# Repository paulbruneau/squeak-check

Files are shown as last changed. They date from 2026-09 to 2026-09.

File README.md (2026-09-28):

# Squeak Check!

A bench tester for Midway's Cheap Squeak Deluxe, Sounds Good and Turbo Cheap Squeak arcade sound boards (Spy Hunter, Rampage, Xenophobe, Sarge and more). Power a sound board on the bench, dial a sound 0–F, press PLAY, and hear it on line out, with no game CPU board, harness or cabinet.

By Ethical Paul.

**Website:** the full write-up (how the boards work, pinouts, hook-up diagram, history) is in `index.html`, published with GitHub Pages.

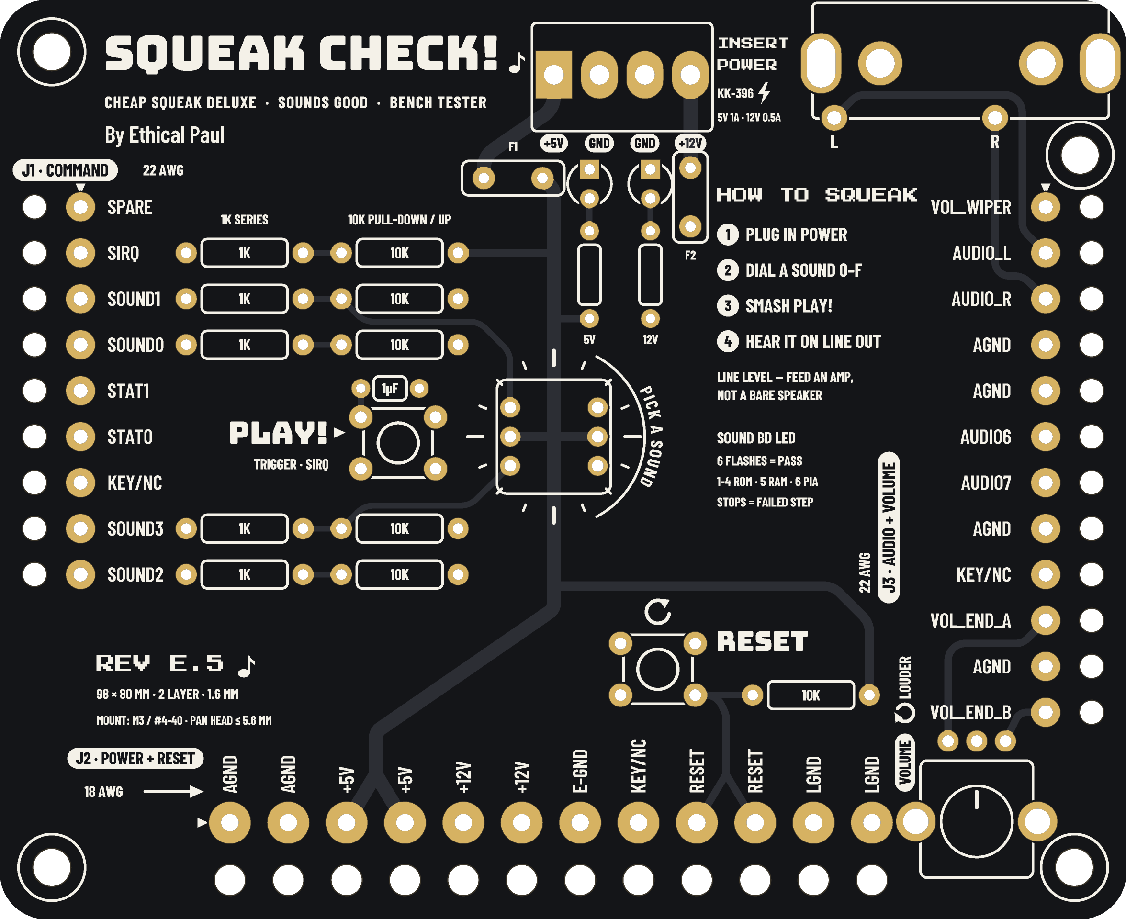
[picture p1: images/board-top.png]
Squeak Check Rev E.5


## Files

| Path | What it is |
| --- | --- |
| `fab/SqueakCheck_RevE5_Gerbers.zip` | Gerbers and drill files, Rev E.5 (98 × 80 mm, 2 layers, 1.6 mm) |
| `fab/Schematic_RevE5.pdf` | Schematic, drawn from and checked against the board netlist |
| `fab/KiCad/` | KiCad 8 schematic and PCB, generated from the board data (refill the zone and run DRC after opening) |
| `fab/BOM.csv` | Bill of materials with Mouser part numbers |
| `fab/Harness_Pin_Map.csv` | Every harness hole: connector, pin, label, net, position |
| `fab/README.txt` | Revision history and verification notes |
| `index.html`, `images/` | The website |

## Ordering boards

Upload the Gerber zip to any 2-layer PCB fab: FR-4, 1.6 mm, 1 oz copper, any mask colour, white silk, HASL or ENIG.

## Rights

© 2026 Ethical Paul. All rights reserved. No license is granted yet; ask before reusing the files.

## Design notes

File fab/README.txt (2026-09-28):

SQUEAK CHECK! — Midway sound board bench tester — REV E.5
By Ethical Paul
=========================================================

WHAT IT TESTS
-------------
Verified against the original Bally/Midway schematics (Spy Hunter, Rampage/Star
Guards and Sarge manuals). All three boards share the same J1/J2/J3 pinout and the
same command interface (4 sound-select bits + SIRQ strobe, 2 status bits back):

  Cheap Squeak Deluxe  A080-91671 (68000)   Spy Hunter, Turbo Tag (proto)
  Sounds Good          A080-91671-G000 PCB  Rampage, Power Drive, Star Guards,
                       (a later revision of  Xenophobe, Spy Hunter II, Blasted,
                        the same bare board) Intl. Team Laser (proto)
  Turbo Cheap Squeak   (6809)               Sarge, Max RPM, Demolition Derby,
                                            Spy Hunter II (2nd board)

NOT compatible: Super Sound I/O (SSIO), and the Williams System 11 boards in
Arch Rivals / Pigskin / Tri-Sports. Pinball-era Bally boards (Cheap Squeak,
Sounds Deluxe, pinball TCS) use different harnesses and were not checked.

REV E.5: POWER PROTECTION AND INDICATORS (review feedback).
- F1 (Bourns MF-R135, 1.35 A hold) on +5 V and F2 (MF-R050, 0.5 A hold) on +12 V:
  resettable fuses right after the power header, so a shorted sound board
  can't cook the tester's traces or connector.
- D1/D2 green LEDs on +5 V and +12 V, AFTER the fuses (1k / 3.3k, ~3 mA): a dark
  LED means no supply or a tripped fuse.
- Suggested supply printed on the board: 5 V 1 A, 12 V 0.5 A (estimated from
  the sound board's chips; measure your own board).
- Mounting note on the silk: M3 or #4-40, pan head no bigger than 5.6 mm.
- LED self-test legend moved into the how-to panel to make room.
Harness holes, pin order, names and every sound-board signal are unchanged.

REV E.4: BOARD NARROWED 108 -> 98 MM. J1 stays on the left edge; the resistor
block tucked in against the J1 labels and everything else slid left (J2, J3, pot,
RCA jacks and power header move as groups, with pitches, hole sizes, pin order and
labels all unchanged). +12V now runs between the SOUND2 trace and the RESET
button on the back. Netlist identical to E.3.

REV E.3: VOLUME POT ON THE BOARD. The J5 A/W/B wire pads are gone; RV1 (Bourns
PTV09A-4020U-B102, 1k linear, 9 mm, vertical 20 mm knurled shaft
you turn by hand - no knob needed) sits in the
bottom-right corner, wired pin 1 = VOL_END_B (J3-12), pin 2 = VOL_WIPER (J3-1),
pin 3 = VOL_END_A (J3-10) so turning it CLOCKWISE = LOUDER (the MC3340 attenuates
more as the wiper voltage rises). Its two side tabs are soldered to ground for
strength. Every other net, hole and label is unchanged from E.2. Part numbers in
BOM.csv are Mouser numbers.

REV E.2 (layout): PLAY button and its debounce cap moved right beside the hex
dial; "By Ethical Paul" added under the title. No circuit change from E.1.

REV E.1 CHANGES (from Rev E / Rev D5)
------------------------------------
1. RESET POLARITY FIXED. J2-9/10 is active-LOW on all three boards (e.g. CSD:
   100k pull-up -> 40106 -> 74LS04 -> diodes pull the 68000 RST/HALT low). Rev D5
   held RESET low through 10k, which would keep the board in reset permanently.
   Now: RRST (10k) pulls RESET up to +5V; the RESET button pulls it to GND.
2. SIRQ polarity hardwired "fire low"; JP1 removed. All three boards idle SIRQ
   high (100k on-board pull-up) and the same game hardware drives them with the
   same signal (Spy Hunter II feeds a Sounds Good and a TCS from the same control
   bits). RIRQ (10k) pulls SIRQ up to +5V; PLAY pulls it to GND.
3. PLAY debounce: C1 1 uF across the button (~10 ms with RIRQ).
4. E-GND (J2-7) tied to GND. Sounds Good grounds it on-board; CSD/TCS use it as
   the return for their input filter capacitors.
Harness hole sizes, pin order, duplicate pins and all silk names are unchanged.

USING IT
--------
Power-up: the sound board's green LED flashes once per passed self-test:
  1-4 = ROMs (U7, U8, U17, U18), 5 = RAM (U6, U16), 6 = PIA (U9).
  Six flashes = pass. Where it stops = the failed step. (Star Guards manual.)

Red TEST button ON the sound board: wired to the 68000's interrupt lines
(pulls IPL0-2 -> level 7). What it does is decided by that game's ROMs. On the
sister pinball boards it plays one fixed test sound (a "bong" or an explosion)
or just reboots the board; it is not a cycle through all sounds.

Sound numbers: the connector carries 4 bits per strobe. The boards' firmware
generally treats commands as pairs of nibbles ("command followed by command"),
so a single dial+PLAY press sends one nibble. Try single presses first; for other
sounds, dial the first nibble, press PLAY, dial the second, press PLAY. The exact
command list lives in each game's sound ROMs and is not documented in MAME.

Start with the VOLUME knob turned down (fully counter-clockwise). Line-level mono audio
appears on both RCA jacks; feed an amplifier or powered speaker.

VERIFICATION
------------
Raster DRC at 0.04 mm: 0 shorts, 0 opens, 0 clearance < 0.30 mm, 0 islands.
Netlist = Rev D5 original + the four E.1 changes + the on-board pot (E.3),
checked pin by pin.
Gerbers re-read with gerbonara and diffed against the checked geometry:
0 mismatches on copper, mask and silk. (No KiCad/Altium DRC available here —
preview the zip in your fab's Gerber viewer before ordering.)

ORDERING
--------
2 layers, FR-4, 1.6 mm, 1 oz, any mask colour, white silk, ENIG or HASL.
98 x 80 mm. Upload the Gerbers/ folder zipped.

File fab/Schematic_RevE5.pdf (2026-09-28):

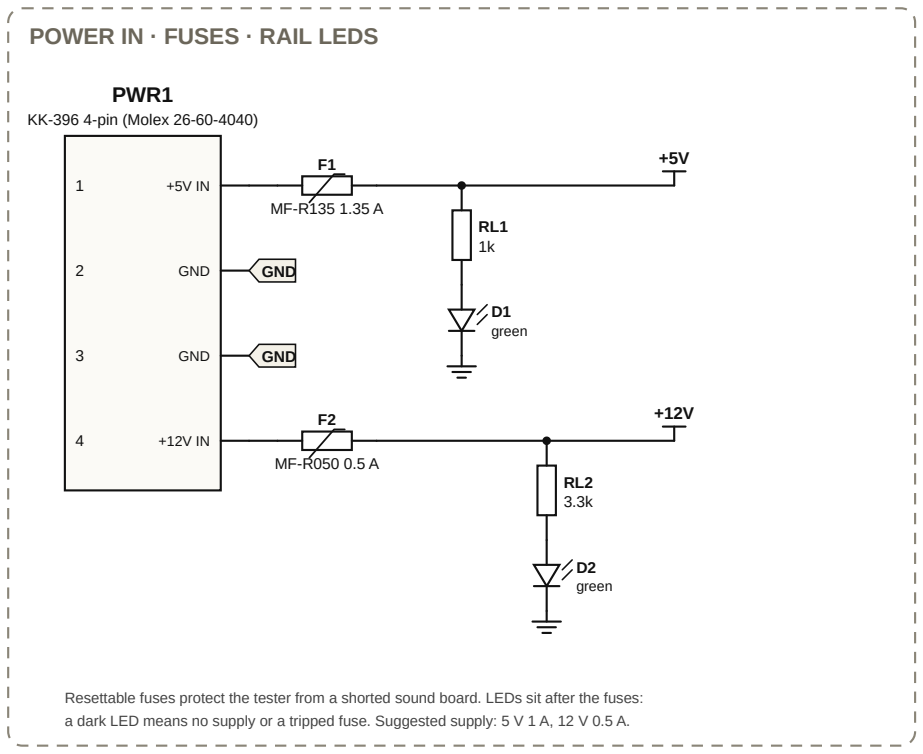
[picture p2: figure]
POWER IN · FUSES · RAIL LEDS; PWR1; KK-396 4-pin (Molex 26-60-4040); GND; D1 green; D2 green

Resettable fuses protect the tester from a shorted sound board. LEDs sit after the fuses: a dark LED means no supply or a tripped fuse. Suggested supply: 5 V 1 A, 12 V 0.5 A.

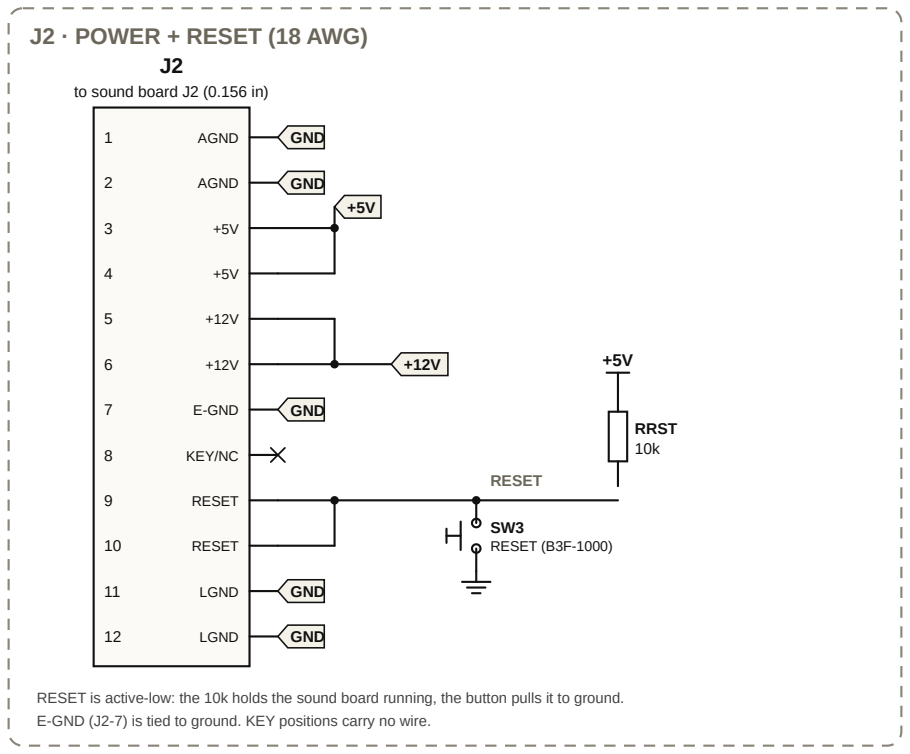
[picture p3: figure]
J2 · POWER + RESET (18 AWG) J2; to sound board J2 (0.156 in); AGND; E-GND; KEY/NC; RESET; LGND; GND; RRST 10k; SW3 RESET (B3F-1000)

RESET is active-low: the 10k holds the sound board running, the button pulls it to ground. E-GND (J2-7) is tied to ground. KEY positions carry no wire.

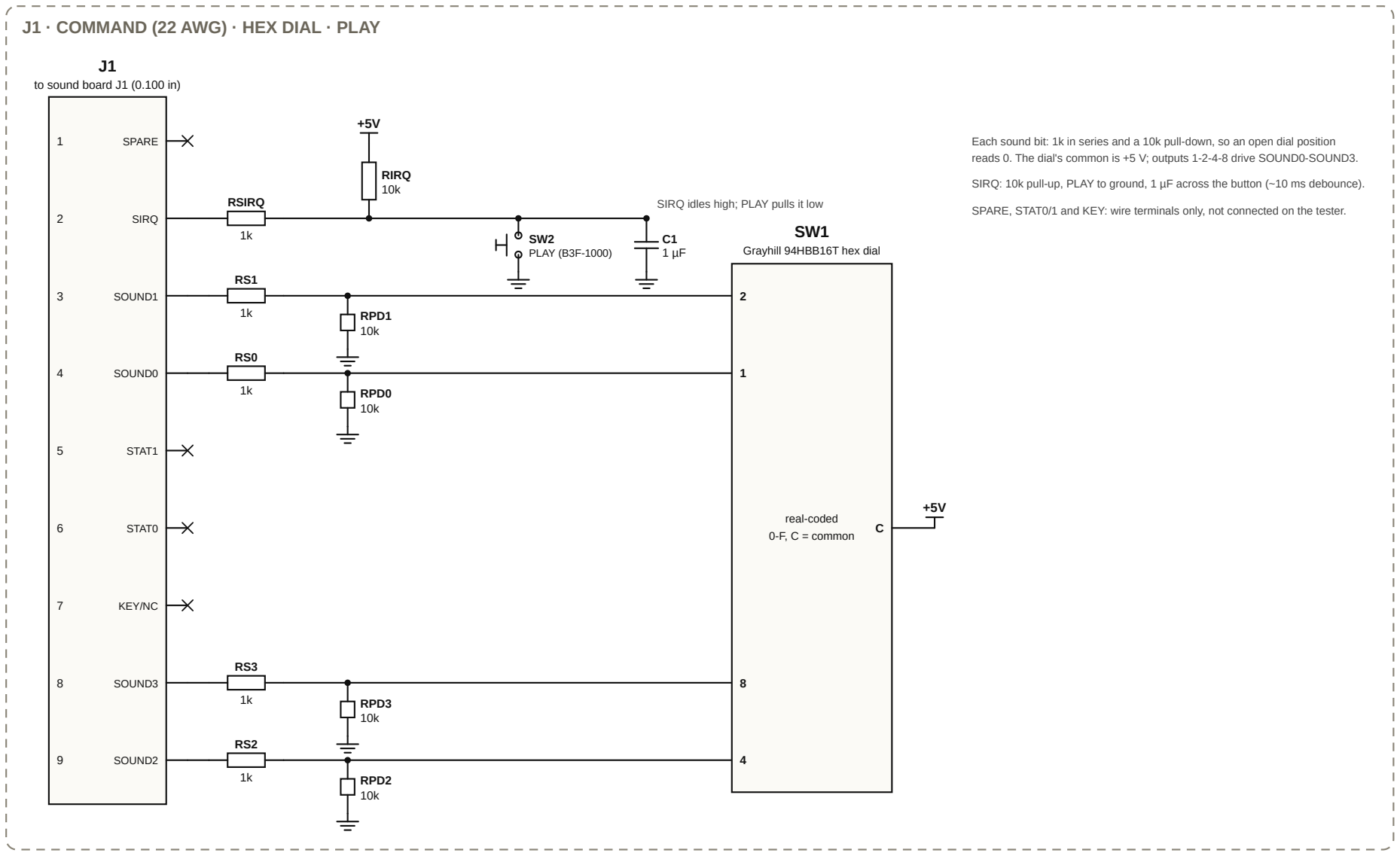
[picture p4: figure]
J1 · COMMAND (22 AWG) · HEX DIAL · PLAY; to sound board J1 (0.100 in); SPARE; SIRQ; SOUND1; SOUND0; STAT1; STAT0; KEY/NC; SOUND3; SOUND2; RPD0; RPD1; RPD2; RPD3; Grayhill 94HBB16T hex dial; real-coded 0-F, C = common; RSIRQ; RIRQ 10k; SW2 PLAY (B3F-1000); SIRQ idles high; PLAY pulls it low

Each sound bit: 1k in series and a 10k pull-down, so an open dial position reads 0. The dial's common is +5 V; outputs 1-2-4-8 drive SOUND0-SOUND3.

SPARE, STAT0/1 and KEY: wire terminals only, not connected on the tester.

SIRQ: 10k pull-up, PLAY to ground, 1 µF across the button (~10 ms debounce).

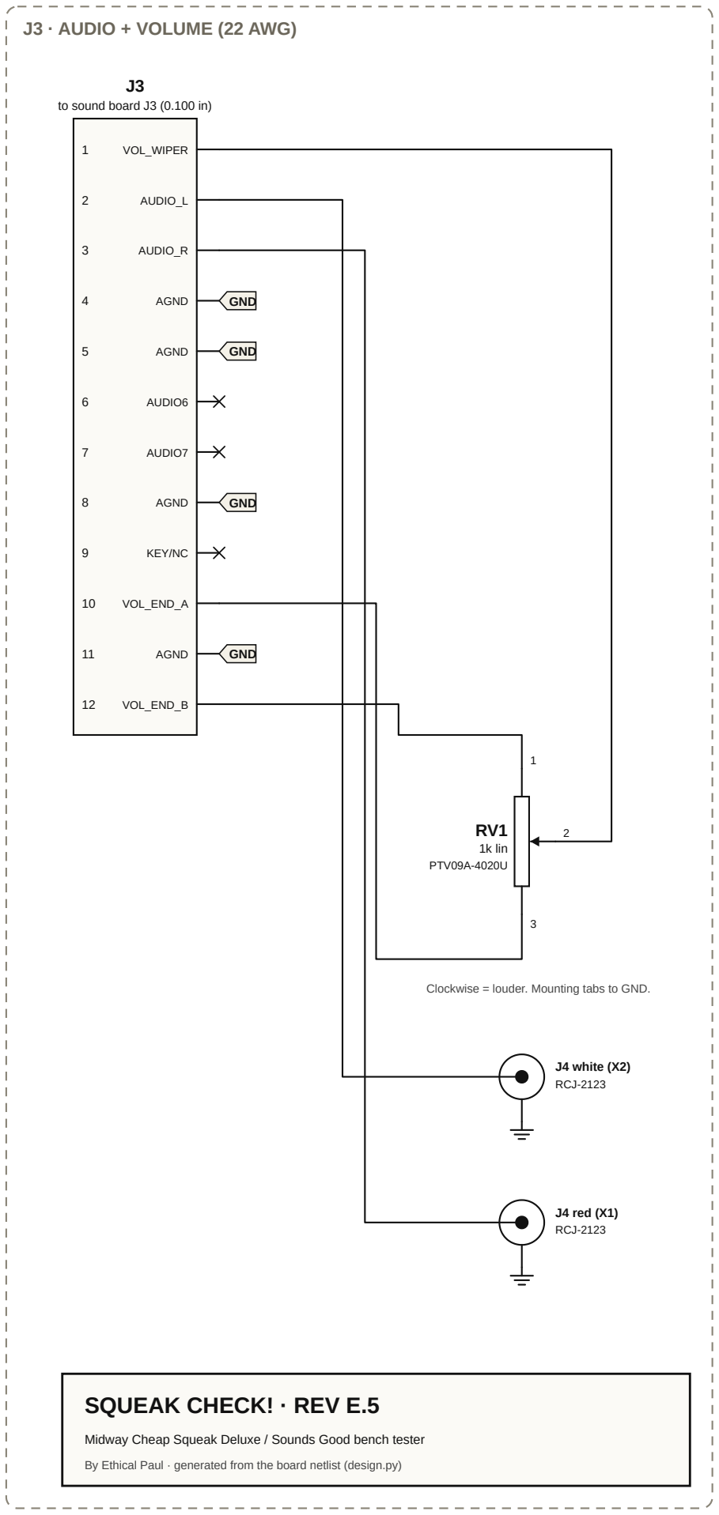
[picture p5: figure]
J3 · AUDIO + VOLUME (22 AWG); to sound board J3 (0.100 in); VOL_WIPER; AUDIO_L; AUDIO_R; AGND; AUDIO6; AUDIO7; KEY/NC; VOL_END_A; VOL_END_B; GND; 1k lin PTV09A-4020U; J4 white (X2) RCJ-2123; J4 red (X1) RCJ-2123; SQUEAK CHECK! · REV E.5

Clockwise = louder. Mounting tabs to GND.

Midway Cheap Squeak Deluxe / Sounds Good bench tester

By Ethical Paul · generated from the board netlist (design.py)

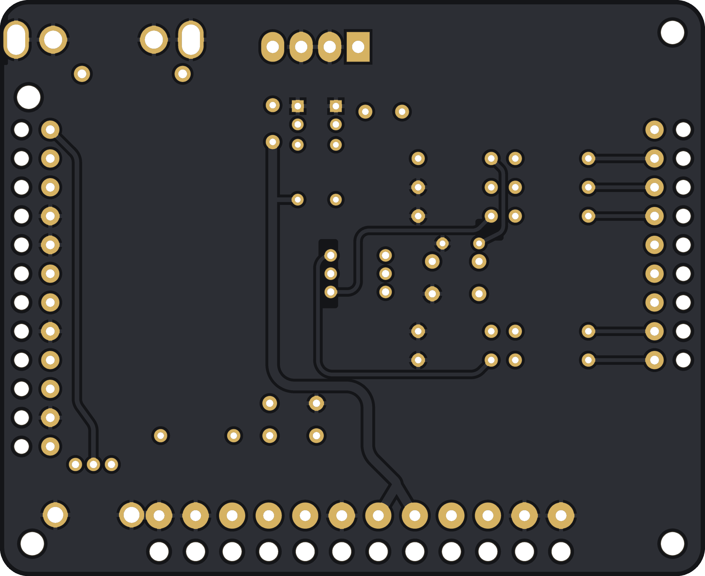
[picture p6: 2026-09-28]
images/board-bottom.png

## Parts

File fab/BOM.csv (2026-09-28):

Ref | Qty | Description | Manufacturer | Mfr Part # | Mouser # | Unit price (Mouser; Sept 2026) | Notes
--- ON THE BOARD ---
SW1 | 1 | 16-pos hex rotary DIP switch (coded) | Grayhill | 94HBB16T | 706-94HBB16T | $7.02 | 0.100" pitch, 0.300" rows
SW2,SW3 | 2 | 6x6 mm THT tactile switch | Omron | B3F-1000 | 653-B3F-1000 | $0.34 | SW2 = PLAY, SW3 = RESET. Wired across a diagonal pad pair
RV1 | 1 | Volume pot, 9 mm, 1k linear, vertical 20 mm KNURLED insulated shaft (turn by finger, no knob needed) | Bourns | PTV09A-4020U-B102 |  | ~$0.46-0.94 (Octopart, Sept 2026) | Same footprint as the flatted-shaft version. Listed at Mouser; Mouser # likely 652-PTV09A-4020UB102 (confirm on their site)
C1 | 1 | 1 uF 50 V X7R ceramic, radial, 5.08 mm | KEMET | C330C105K5R5TA | 80-C330C105K5R | $0.54 | PLAY debounce
RSIRQ,RS0,RS1,RS2,RS3 | 5 | 1k 1/4 W 1% metal film, axial | YAGEO | MFR-25FBF52-1K | 603-MFR-25FBF52-1K | $0.10 | 10.16 mm (0.4 in) lead spacing
RIRQ,RPD0,RPD1,RPD2,RPD3,RRST | 6 | 10k 1/4 W 1% metal film, axial | YAGEO | MFR-25FBF52-10K | 603-MFR-25FBF52-10K | $0.10 | RIRQ = SIRQ pull-up; RRST = RESET pull-up
PWR1 | 1 | KK-396 4-pos vertical friction-lock header | Molex | 26-60-4040 | 538-26-60-4040 | $0.44
J4 | 1 | Dual RCA jack (red/white) right angle | Same Sky | RCJ-2123 | 490-RCJ-2123 | $2.33
F1 | 1 | PTC resettable fuse, +5 V: 1.35 A hold / 2.7 A trip, radial 5.1 mm, 0.065-0.17 ohm | Bourns | MF-R135 | 652-MF-R135 (confirm) |  | Rev E.5. Drops ~0.1 V at 1 A; set the bench supply to 5.1 V if you want 5.0 V at the board
F2 | 1 | PTC resettable fuse, +12 V: 0.5 A hold / 1.0 A trip, radial 5.1 mm | Bourns | MF-R050 | 652-MF-R050 (confirm) |  | Rev E.5
D1,D2 | 2 | LED 3 mm green, diffused | Kingbright | WP710A10GD | 604-WP710A10GD (confirm) |  | Rev E.5 rail indicators, after the fuses. Square pad / flat side = cathode
RL1 | 1 | 1k 1/6 W 1% metal film, 7.62 mm spacing | YAGEO | MFR-12FTF52-1K | 603-MFR-12FTF52-1K |  | D1 (+5 V) current limit, ~3 mA
RL2 | 1 | 3.3k 1/6 W 1% metal film, 7.62 mm spacing | YAGEO | MFR-12FTF52-3K3 | 603-MFR-12FTF52-3K3 (confirm) |  | D2 (+12 V) current limit, ~3 mA
--- POWER CABLE (plugs into PWR1) ---
PWR1 mate | 1 | KK-396 4-pos housing | Molex | 09-50-3041 | 538-09-50-3041 | $0.10
PWR1 mate | 4 | KK-396 crimp terminal 18-24 AWG | Molex | 08-50-0106 | 538-08-50-0106 | $0.12
--- HARNESS PLUGS (sound board end) — TE MTA IDC, as on the original Midway harness ---
J1 plug | 1 | MTA-100 IDC receptacle, 9 pos, 22 AWG (red), closed end | TE Connectivity | 3-640440-9 |  |  | Mates with the sound board's .025 sq. posts on 0.100 in pitch. Leave pin 7 (KEY) empty
J3 plug | 1 | MTA-100 IDC receptacle, 12 pos, 22 AWG (red), closed end | TE Connectivity | 4-640440-2 |  |  | 0.100 in pitch. Leave pin 9 (KEY) empty
J2 plug | 1 | MTA-156 IDC receptacle, 12 pos, 18 AWG (orange), feed-through | TE Connectivity | 4-640599-2 |  |  | Mates with .045 sq. posts on 0.156 in pitch. Leave pin 8 (KEY) empty
J2 key | 1 | MTA-156 polarizing key | TE Connectivity | 640629-1 |  |  | Plugs the KEY position so J2 can't go on shifted
--- NOT LOOKED UP ON MOUSER (their site began blocking automated lookups) ---
WIRE22 | 1 | 22 AWG stranded, UL1007 | Alpha Wire | 3051 (colour suffix e.g. BK005) |  |  | J1 and J3 harnesses
WIRE18 | 1 | 18 AWG stranded, UL1007 | Alpha Wire | 3055 (colour suffix e.g. BK005) |  |  | J2 harness
MH1-MH4 | 4 | M3 standoffs + screws | any |  |  |  | Optional; 3.2 mm NPTH corner holes. Keep screw heads <= 5.5 mm dia at the bottom-right hole (next to the pot)

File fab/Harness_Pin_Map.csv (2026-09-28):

Harness | Pin | Silkscreen label | Net on board | Wire | X_mm | Y_mm
J1 | 1 | SPARE | not connected | 22 AWG | 7.00 | 62.00
J1 | 2 | SIRQ | J1_SIRQ | 22 AWG | 7.00 | 58.00
J1 | 3 | SOUND1 | J1_S1 | 22 AWG | 7.00 | 54.00
J1 | 4 | SOUND0 | J1_S0 | 22 AWG | 7.00 | 50.00
J1 | 5 | STAT1 | not connected | 22 AWG | 7.00 | 46.00
J1 | 6 | STAT0 | not connected | 22 AWG | 7.00 | 42.00
J1 | 7 | KEY/NC | not connected | 22 AWG | 7.00 | 38.00
J1 | 8 | SOUND3 | J1_S3 | 22 AWG | 7.00 | 34.00
J1 | 9 | SOUND2 | J1_S2 | 22 AWG | 7.00 | 30.00
J2 | 1 | AGND | GND | 18 AWG | 20.00 | 8.40
J2 | 2 | AGND | GND | 18 AWG | 25.08 | 8.40
J2 | 3 | +5V | +5V | 18 AWG | 30.16 | 8.40
J2 | 4 | +5V | +5V | 18 AWG | 35.24 | 8.40
J2 | 5 | +12V | +12V | 18 AWG | 40.32 | 8.40
J2 | 6 | +12V | +12V | 18 AWG | 45.40 | 8.40
J2 | 7 | E-GND | GND | 18 AWG | 50.48 | 8.40
J2 | 8 | KEY/NC | not connected | 18 AWG | 55.56 | 8.40
J2 | 9 | RESET | RESET | 18 AWG | 60.64 | 8.40
J2 | 10 | RESET | RESET | 18 AWG | 65.72 | 8.40
J2 | 11 | LGND | GND | 18 AWG | 70.80 | 8.40
J2 | 12 | LGND | GND | 18 AWG | 75.88 | 8.40
J3 | 1 | VOL_WIPER | VOL_W | 22 AWG | 91.00 | 62.00
J3 | 2 | AUDIO_L | AUD_L | 22 AWG | 91.00 | 58.00
J3 | 3 | AUDIO_R | AUD_R | 22 AWG | 91.00 | 54.00
J3 | 4 | AGND | GND | 22 AWG | 91.00 | 50.00
J3 | 5 | AGND | GND | 22 AWG | 91.00 | 46.00
J3 | 6 | AUDIO6 | not connected | 22 AWG | 91.00 | 42.00
J3 | 7 | AUDIO7 | not connected | 22 AWG | 91.00 | 38.00
J3 | 8 | AGND | GND | 22 AWG | 91.00 | 34.00
J3 | 9 | KEY/NC | not connected | 22 AWG | 91.00 | 30.00
J3 | 10 | VOL_END_A | VOL_A | 22 AWG | 91.00 | 26.00
J3 | 11 | AGND | GND | 22 AWG | 91.00 | 22.00
J3 | 12 | VOL_END_B | VOL_B | 22 AWG | 91.00 | 18.00

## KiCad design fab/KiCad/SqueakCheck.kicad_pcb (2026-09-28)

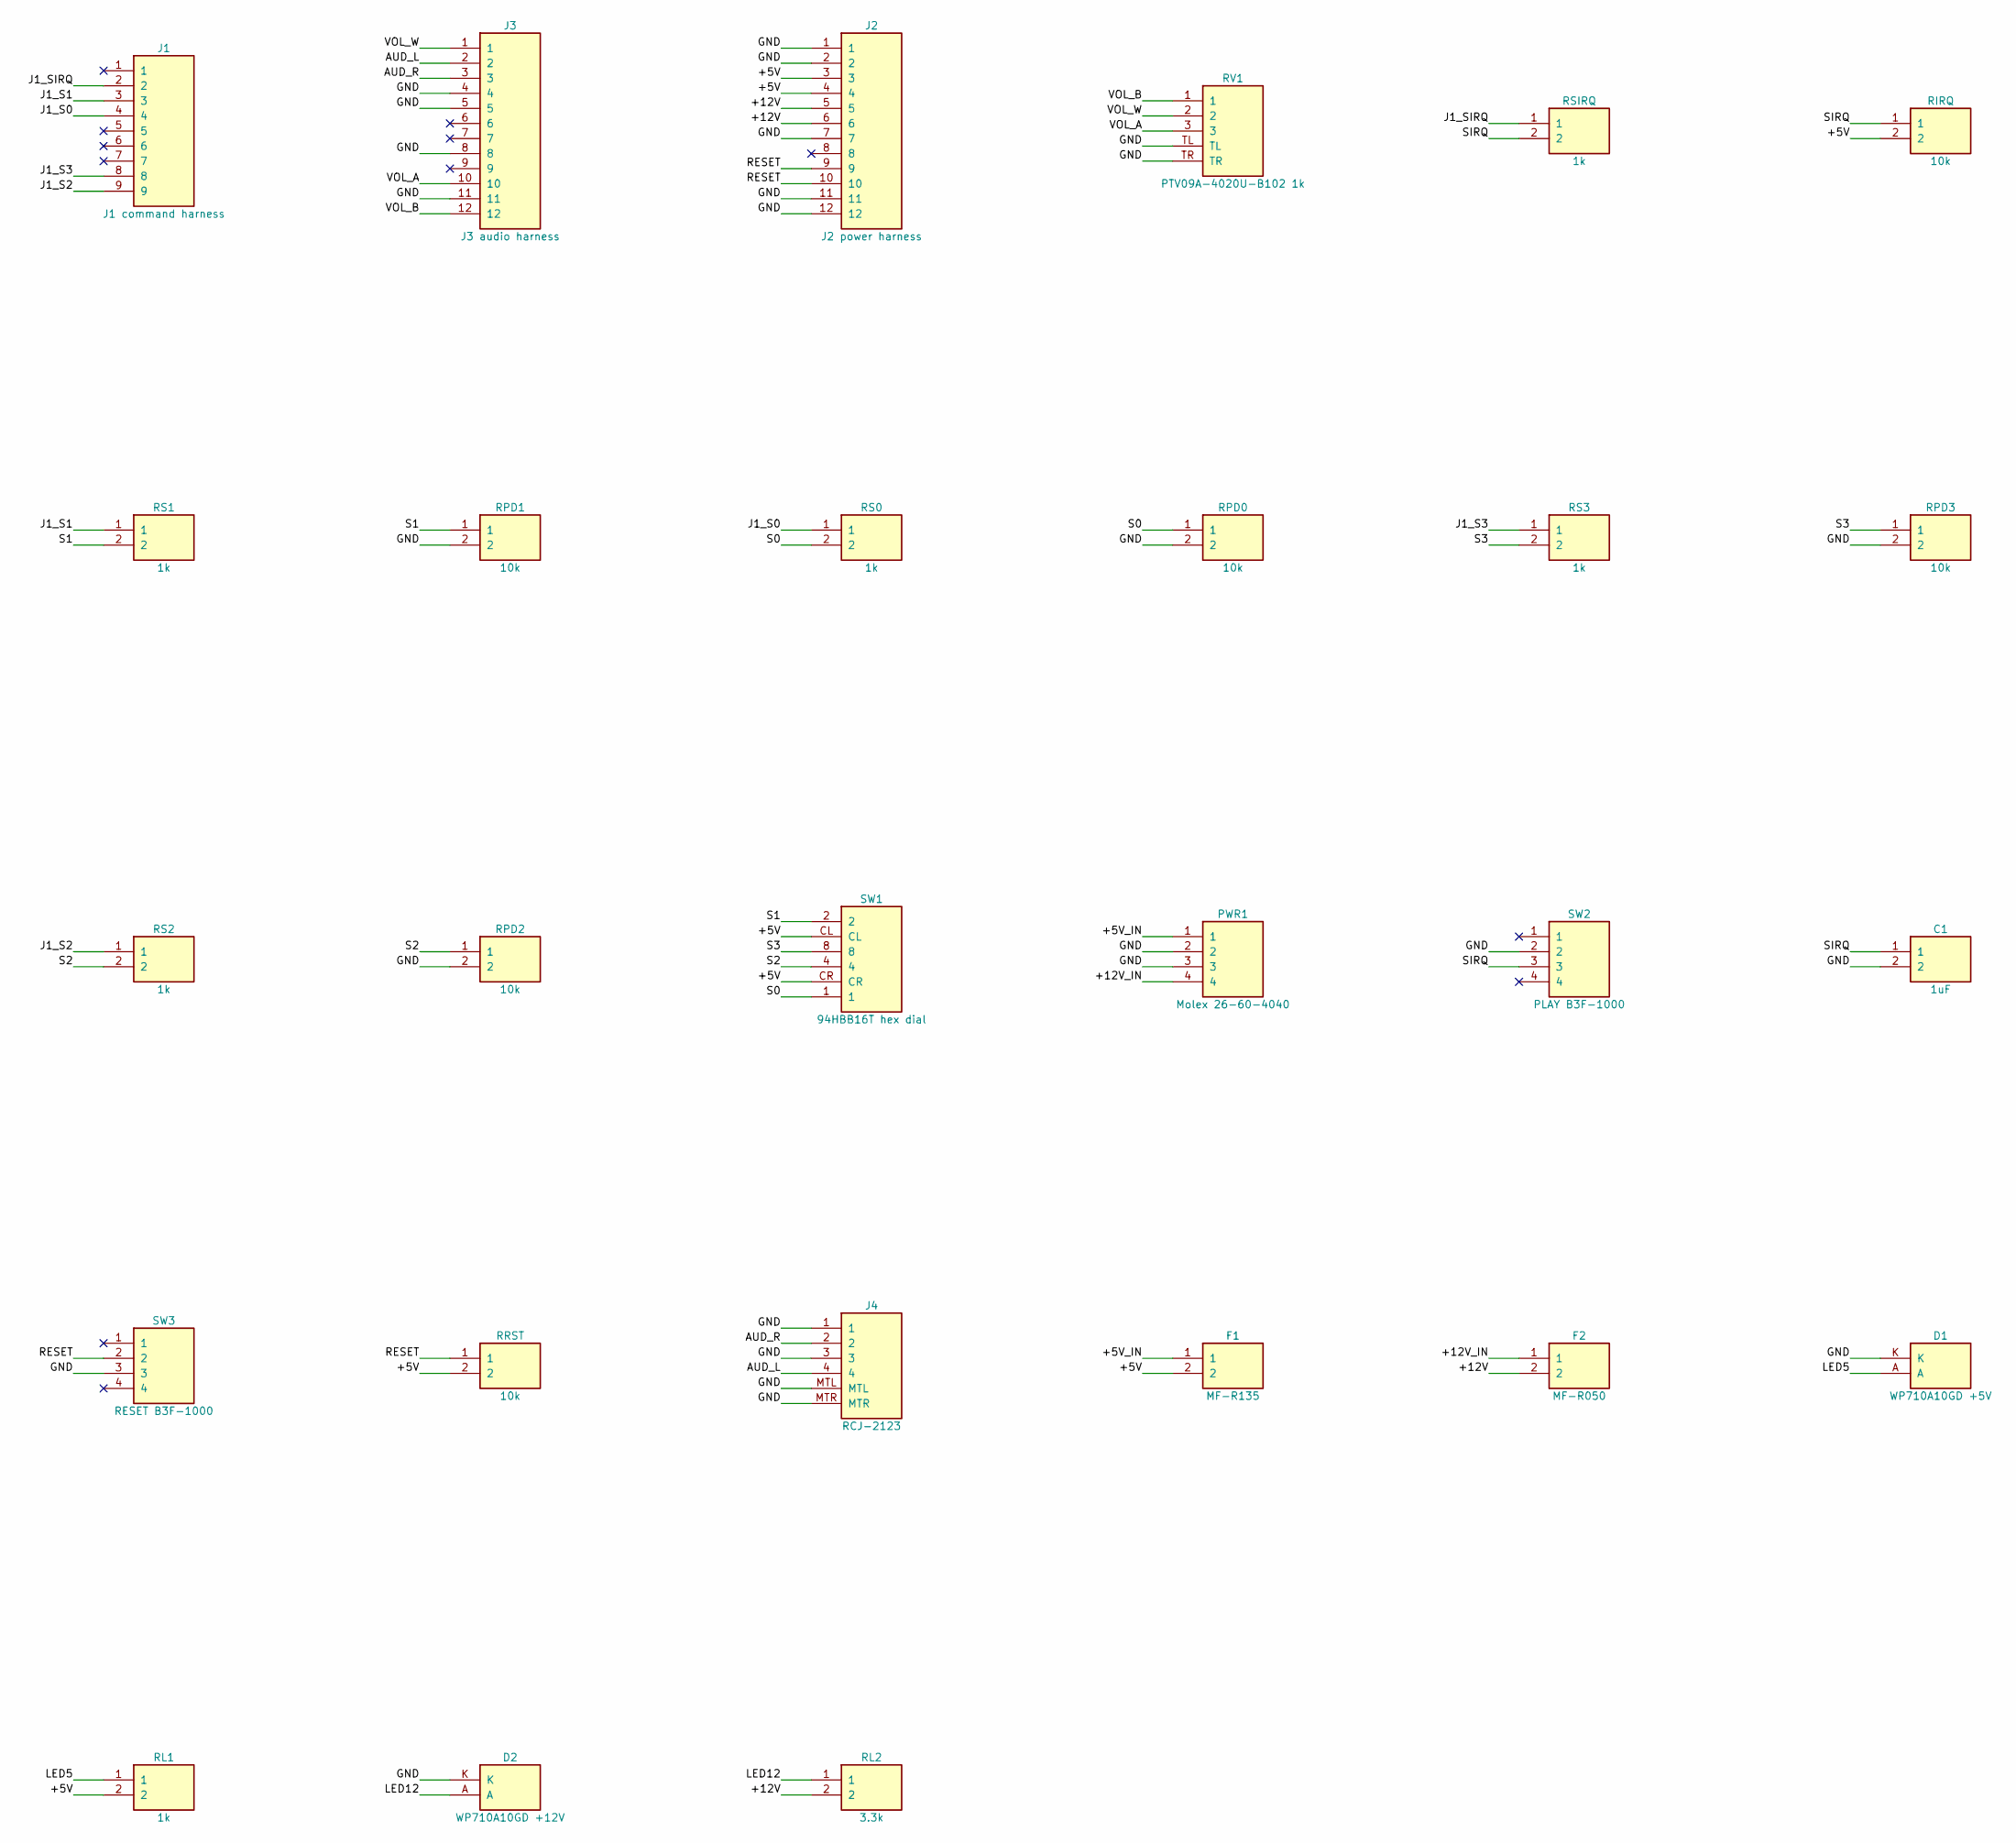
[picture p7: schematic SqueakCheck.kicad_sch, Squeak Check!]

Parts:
C1: 1uF; C1
D1: WP710A10GD +5V; D1
D2: WP710A10GD +12V; D2
F1: MF-R135; F1
F2: MF-R050; F2
J1: J1 command harness; J1
J2: J2 power harness; J2
J3: J3 audio harness; J3
J4: RCJ-2123; J4
PWR1: Molex 26-60-4040; PWR1
RIRQ: 10k; RIRQ
RL1: 1k; RL1
RL2: 3.3k; RL2
RPD0: 10k; RPD0
RPD1: 10k; RPD1
RPD2: 10k; RPD2
RPD3: 10k; RPD3
RRST: 10k; RRST
RS0: 1k; RS0
RS1: 1k; RS1
RS2: 1k; RS2
RS3: 1k; RS3
RSIRQ: 1k; RSIRQ
RV1: PTV09A-4020U-B102 1k; RV1
SW1: 94HBB16T hex dial; SW1
SW2: PLAY B3F-1000; SW2
SW3: RESET B3F-1000; SW3

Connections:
+5V: F1.2, J2.3, J2.4, RIRQ.2, RL1.2, RRST.2, SW1.CL, SW1.CR
+5V_IN: F1.1, PWR1.1
+12V: F2.2, J2.5, J2.6, RL2.2
+12V_IN: F2.1, PWR1.4
AUD_L: J3.2, J4.4
AUD_R: J3.3, J4.2
GND: C1.2, D1.K, D2.K, J2.1, J2.2, J2.7, J2.11, J2.12, J3.4, J3.5, J3.8, J3.11, J4.1, J4.3, J4.MTL, J4.MTR, PWR1.2, PWR1.3, RPD0.2, RPD1.2, RPD2.2, RPD3.2, RV1.TL, RV1.TR, SW2.2, SW3.3
J1_S0: J1.4, RS0.1
J1_S1: J1.3, RS1.1
J1_S2: J1.9, RS2.1
J1_S3: J1.8, RS3.1
J1_SIRQ: J1.2, RSIRQ.1
LED5: D1.A, RL1.1
LED12: D2.A, RL2.1
RESET: J2.9, J2.10, RRST.1, SW3.2
S0: RPD0.1, RS0.2, SW1.1
S1: RPD1.1, RS1.2, SW1.2
S2: RPD2.1, RS2.2, SW1.4
S3: RPD3.1, RS3.2, SW1.8
SIRQ: C1.1, RIRQ.1, RSIRQ.2, SW2.3
VOL_A: J3.10, RV1.3
VOL_B: J3.12, RV1.1
VOL_W: J3.1, RV1.2

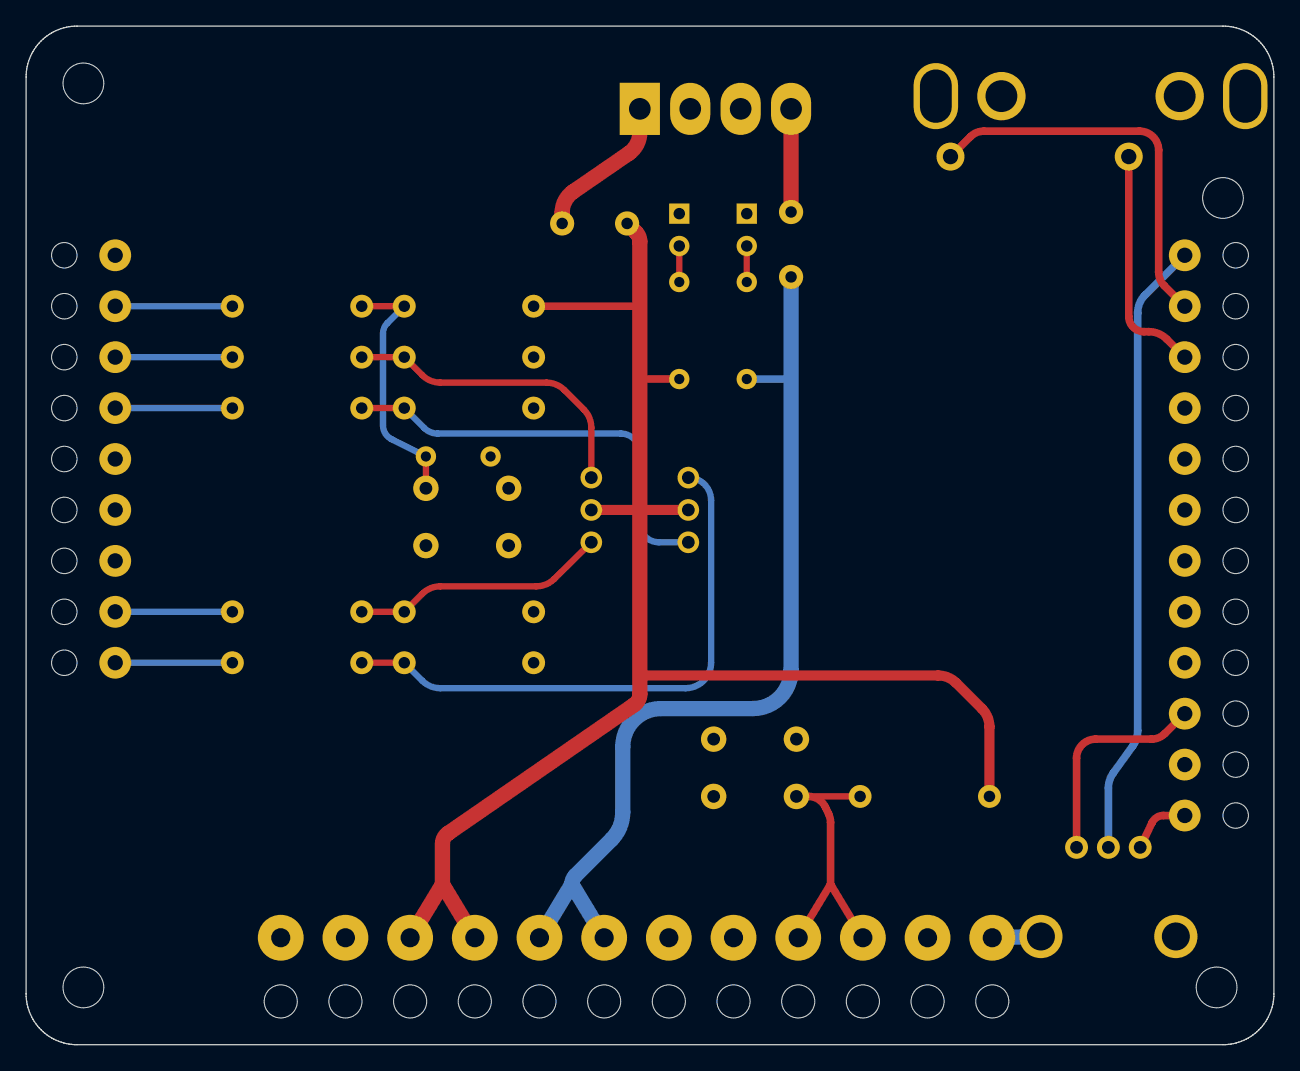
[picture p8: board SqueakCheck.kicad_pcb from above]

Board: 2 copper layers, 98.0 x 80.0 mm, 64 parts (0 on the bottom side), 23 nets.

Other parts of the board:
H1, H2, H3, H4, H5, H6, H7, H8, H9, H10, H11, H12, H13, H14, H15, H16, H17, H18, H19, H20, H21: hole 2; NPTH_2mm
H22, H23, H24, H25, H26, H27, H28, H29, H30, H31, H32, H33: hole 2.6; NPTH_2.6mm
H34, H35, H36, H37: hole 3.2; NPTH_3.2mm

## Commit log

2026-09-28 Add Squeak Check Rev E.4 website, Gerbers, BOM and pin map
    Claude-Session: https://claude.ai/code/session_01UH3jSvJNsrzsb5NFtL9fUT
    [BOM.csv, Harness_Pin_Map.csv]
2026-09-28 Rev E.5: resettable fuses and rail LEDs, schematic PDF, KiCad files
    Adds MF-R135/MF-R050 PTC fuses after the power header, green +5 V / +12 V
    LEDs after the fuses, supply and mounting-screw notes on the silkscreen,
    a schematic checked against the board netlist, and generated KiCad 8
    schematic/PCB files.
    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
    [BOM.csv, SqueakCheck.kicad_pcb, SqueakCheck.kicad_sch]
2026-10-10 Rev E.6: hex dial fits with its 0 at the top
    The Grayhill 94HBB16T fits SW1's holes either way round. E.5's pin map
    assumed 0 toward the bottom, so a switch fitted with 0 at the top swapped
    SOUND0<->SOUND1 and SOUND2<->SOUND3. E.6 turns the footprint's pin numbers
    180 degrees and swaps the four sound tracks where they meet the resistors;
    hole positions are unchanged.
    - Gerbers: rerouted S0-S3 tracks (filleted), three small back-pour
    keep-outs, silk "0"/"8" at the dial, REV E.6
    - KiCad PCB/schematic updated to match (tracks verified against Gerbers)
    - Schematic PDF: rev and SW1 orientation note
    - Board renders, website, README, fab notes and BOM updated
    - Raster DRC: netlist matches, no is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
2026-10-10 Rev E.6 follow-ups from the independent check
    - fab/README.txt: correct clearance (0.50 mm top) and thin-copper notes,
    update the E.4 note for the rerouted bottom trace
    - BOM and website: mounting screw head 5.6 mm, matching the silkscreen
    - Schematic PDF: drop the hidden "E.5" text under the E.6 title
    - KiCad PCB: remove the duplicate GND net declaration
    Claude-Session: https://claude.ai/code/session_012k9RuKwdgXoTh4kCDBBGuh
2026-10-10 Rev E.6: silkscreen text at least 1.1 mm tall
    Every label under 1.1 mm (smallest was 0.72 mm) is scaled in place to a
    1.1 mm capital height, strokes now about 0.2 mm. "5V 1A · 12V 0.5A" splits
    onto two lines to clear the RCA jack outline. Checked: no silk on pads,
    0.2 mm or more to other silk except the power tags' original spacing;
    copper, mask and drills unchanged.
    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
2026-10-11 Rev E.6: add contact email beside the credit line
    "By Ethical Paul · paul@ethicalpaul.com" on the silkscreen, same height
    and baseline as the credit; 0.4 mm or more from other silk, no copper
    or drill change.
    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
2026-10-11 Rev E.6: credits and supported boards as two stacks
    Left: By Ethical Paul / paul@ethicalpaul.com. Right: CHEAP SQUEAK DELUXE /
    SOUNDS GOOD / TURBO CHEAP SQUEAK at 1.3 mm (was a 1.0 mm one-line
    subtitle). Letters reused from the original subtitle; 0.6 mm or more to
    other silk; no copper or drill change.
    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
2026-10-11 Email in the credit's font; add board tools and font to the repo
    - paul@ethicalpaul.com redrawn in Barlow Condensed SemiBold, the face of
    "By Ethical Paul" (matched by overlay, 93% pixel agreement)
    - tools/: the Gerber reader, DRC, renderer and silkscreen scripts used for
    Rev E.6, so later changes don't depend on a lost generator
    - fab/fonts/: BarlowCondensed-SemiBold.ttf with its OFL licence
    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
2026-10-11 Rev E.6: larger, centred REV / size / mounting block
    Scaled 1.6x (REV 2.2 mm, notes 1.8 mm) and centred between the SOUND2
    row and the J2 labels. No copper or drill change.
    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
2026-10-11 Rev E.6: larger credit and email
    "By Ethical Paul" 1.40 -> 1.75 mm, email 1.20 -> 1.47 mm, cap top level
    with the supported-boards list. No copper or drill change.
    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
2026-10-11 tools: render_board.py can draw green solder mask
    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
2026-10-11 Website board pictures in green solder mask
    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
2026-10-11 Number resistors R1-R13 instead of descriptive names
    RSIRQ R1, RIRQ R2, RS1 R3, RPD1 R4, RS0 R5, RPD0 R6, RS3 R7, RPD3 R8,
    RS2 R9, RPD2 R10, RL1 R11, RL2 R12, RRST R13. Updated in the BOM (with
    each resistor's job in the notes), KiCad PCB and schematic, schematic
    PDF, website parts table and fab notes. Silkscreen and Gerbers are
    unchanged (the board prints values, not references). Also fixes an
    unquoted comma in the BOM's mounting-hole note.
    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
2026-10-13 Add Cheap Squeak Deluxe schematic as a reference
    Midway A080-91671 schematic sheet (from the Spy Hunter manual),
    kept alongside the tester for DAC and connector reference.
    Claude-Session: https://claude.ai/code/session_01CsTALYjpup5LmmiDPDAqK8
2026-10-14 Add Squeak Tap: digital audio capture for the Cheap Squeak Deluxe
    New squeak-tap/ folder with a companion project that plugs into the
    CSD's DAC socket (U10) and records the 10-bit DAC values over USB:
    - hardware/: Rev A two-board panel (DAC adapter + Pico capture board,
    mouse-bite tabs), Gerbers, schematic, BOM, ribbon pin map, KiCad 8
    PCB, renders, and the Python generator and DRC used to make them
    - firmware/: Pico / Pico 2 firmware (960 kHz PIO sampler, USB stream)
    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
2026-10-14 Add a Squeak Tap section to the website
    New "Squeak Tap" section (and nav link) before Sources: what the DAC
    adapter and capture board do, why the capture samples at 960 kHz, how
    to record the Spy Hunter theme with Squeak Check, a Rev A "not built
    yet" callout, ordering notes and download cards for the Gerbers,
    schematic, BOM, pin map, firmware and PC tool.
    Panel renders re-made with green mask to match the Squeak Check images.
    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
